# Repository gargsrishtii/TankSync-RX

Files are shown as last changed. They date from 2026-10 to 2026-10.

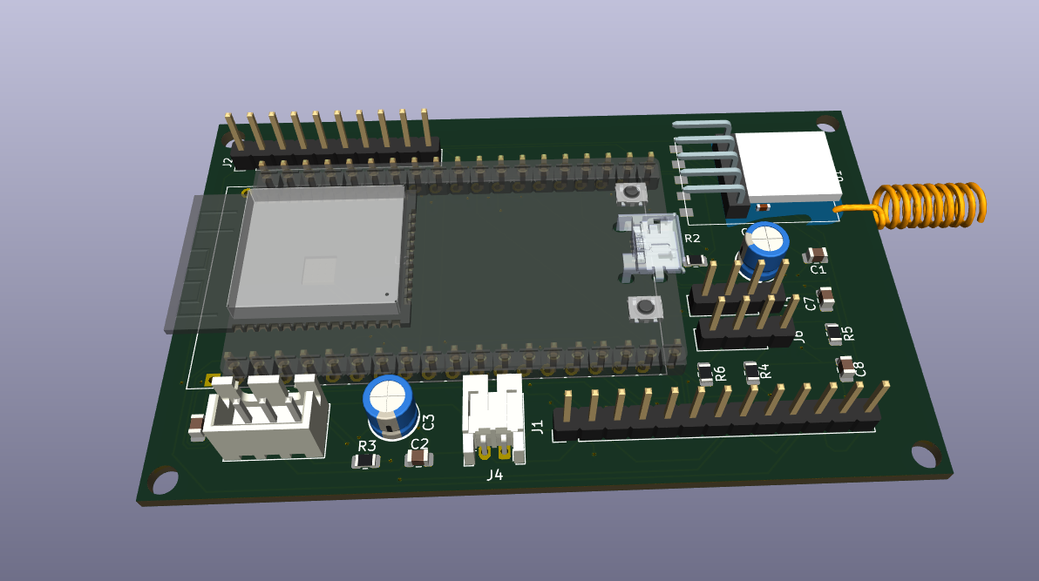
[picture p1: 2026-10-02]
images/3D view.png

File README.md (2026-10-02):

# TankSync RX — PCB Design

> 2-layer receiver board for a wireless tank monitoring system, built around the ESP32-DevKitC-VE and RYLR998 LoRa module. Designed in KiCad 10.0.

---

## Overview

TankSync RX is the receiver-side PCB of a LoRa-based wireless monitoring system. It receives sensor data transmitted over 868/915 MHz LoRa and processes it via an ESP32 for display and relay control.

**Key features:**
- ESP32-DevKitC-VE as the main controller (Wi-Fi + Bluetooth + dual-core)
- RYLR998 LoRa UART module for long-range wireless communication
- 1.3" OLED display connector (4-pin, I2C)
- WS2812B LED data line with 470Ω series resistor
- 3x status LEDs with 330Ω current-limiting resistors
- JST PH 2.0mm power input connector
- JST XH 3-pin connector for external sensor/data interface
- Berg headers (13-pin + 10-pin) for future relay expansion
- Decoupling capacitors on all power rails
- GND copper pour on both layers

---

## Board Specifications

| Parameter | Value |
|---|---|
| Board size | 80 × 50 mm |
| Layers | 2 (F.Cu + B.Cu) |
| PCB thickness | 1.6 mm |
| Design tool | KiCad 10.0 |
| ERC status | 0 errors, 0 warnings |
| DRC status | 0 errors, 0 unconnected |
| Gerbers | Exported and verified |

---

## Schematic

> *See `/schematic/TankSync_RX_Schematic.pdf` for the full schematic.*

Key design decisions:
- **LORA_RST** tied to ESP32 IO12 with a 10KΩ pull-up (R2) to +3V3, allowing software-controlled LoRa reset
- **R3 (470Ω)** series data resistor from IO32 to LED_DATA line (protects ESP32 GPIO from WS2812B inrush)
- **C6, C7, C8 (100nF SMD)** decoupling capacitors placed close to ESP32 power pins
- **C3, C4 (100µF THT)** bulk decoupling on main power rail — these must remain THT (not changed to SMD)
- **J1 (13-pin) and J2 (10-pin)** Berg headers routed to ESP32 for future relay expansion board

---

## Bill of Materials

| Ref | Qty | Value / Part | Package | Description |
|---|---|---|---|---|
| U1 | 1 | RYLR998 | Castellated 5-pin SMD | REYAX 868/915MHz LoRa UART module |
| U2 | 1 | ESP32-DEVKITC-VE | 38-pin THT dual row | Espressif ESP32 dev board |
| C1 | 1 | 10µF | 0805 SMD | Power rail decoupling |
| C2 | 1 | 47µF | 0805 SMD | Power rail decoupling |
| C3, C4 | 2 | 100µF | Radial THT D5.0mm P2.5mm | Bulk decoupling — must stay THT |
| C6, C7, C8 | 3 | 100nF | 0805 SMD | ESP32 pin decoupling |
| R2 | 1 | 10KΩ | 0805 SMD | LORA_RST pull-up |
| R3 | 1 | 470Ω | 0805 SMD | LED data line series resistor |
| R4, R5, R6 | 3 | 330Ω | 0805 SMD | Status LED current limiters |
| J1 | 1 | Berg 13-pin | PinHeader 1x13 2.54mm | Relay expansion header |
| J2 | 1 | Berg 10-pin | PinHeader 1x10 2.54mm | Relay expansion header |
| J3 | 1 | 1.3" OLED | PinHeader 1x04 2.54mm | OLED display connector |
| J4 | 1 | JST PH 2-pin | JST PH S2B 2.0mm | Power input |
| J5 | 1 | JST XH 3-pin | JST XH B3B 2.5mm | External data connector |
| J6 | 1 | LED Panel | PinHeader 1x04 2.54mm | LED panel connector |

---

## Repository Structure

```
tanksync-pcb/
├── README.md
├── LICENSE
├── images/
│   └── 3D view.png
|   ├── TankSync-rx.png
|   ├── pcb-layout.png
├── gerbers/
│   └── TankSync_RX_Gerbers.zip
├── bom/
│   └── Project1.csv
└── kicad/
    ├── Project1.kicad_pro
    ├── Project1.kicad_sch
    ├── Project1.kicad_pcb
    └── Project1.net
```

---

## Gerber Files

The `/gerbers/` folder contains the complete Gerber set ready for fabrication:

| File | Layer |
|---|---|
| Project1-F_Cu.gbr | Front copper |
| Project1-B_Cu.gbr | Back copper |
| Project1-F_Silkscreen.gbr | Front silkscreen |
| Project1-B_Silkscreen.gbr | Back silkscreen |
| Project1-F_Mask.gbr | Front solder mask |
| Project1-B_Mask.gbr | Back solder mask |
| Project1-F_Paste.gbr | Front solder paste |
| Project1-B_Paste.gbr | Back solder paste |
| Project1-Edge_Cuts.gbr | Board outline |
| Project1-job.gbrjob | Gerber job file |

Recommended fab services: JLCPCB, PCBWay, OSH Park (all accept this Gerber format directly).

---

## Custom Library Dependency

This design uses two custom KiCad components from my public library:

- `MyLibrary:RYLR998_Castellated_5P` — REYAX RYLR998 LoRa module
- `MyLibrary:ESP32-DEVKITC-VE` — Espressif ESP32-DevKitC-VE dev board

**To open this project in KiCad**, you need to add the custom library first:
👉 [gargsrishtii/kicad-parts-library](https://github.com/gargsrishtii/kicad-parts-library)

Follow the installation instructions in that repo's README before opening the `.kicad_sch` or `.kicad_pcb` files.

---

## Pre-fab Checklist (Open Items)

- [ ] Zip and verify Gerbers in a Gerber viewer before ordering
- [ ] Confirm J4 JST PH part number against supplier stock
- [ ] Measure enclosure inner diameter against board outline

---

## Design Tool

- **KiCad 10.0** (PCB design)
- **EasyEDA** (cross-reference for component verification)

---

## License

This hardware design is released under **CERN-OHL-P v2** (Permissive Open Hardware License).
Free to use, modify, and manufacture — no share-alike requirement.
See [LICENSE](LICENSE) for full terms.

---

*Part of the TankSync wireless monitoring system project.*
*Custom KiCad library: [gargsrishtii/kicad-parts-library](https://github.com/gargsrishtii/kicad-parts-library)*

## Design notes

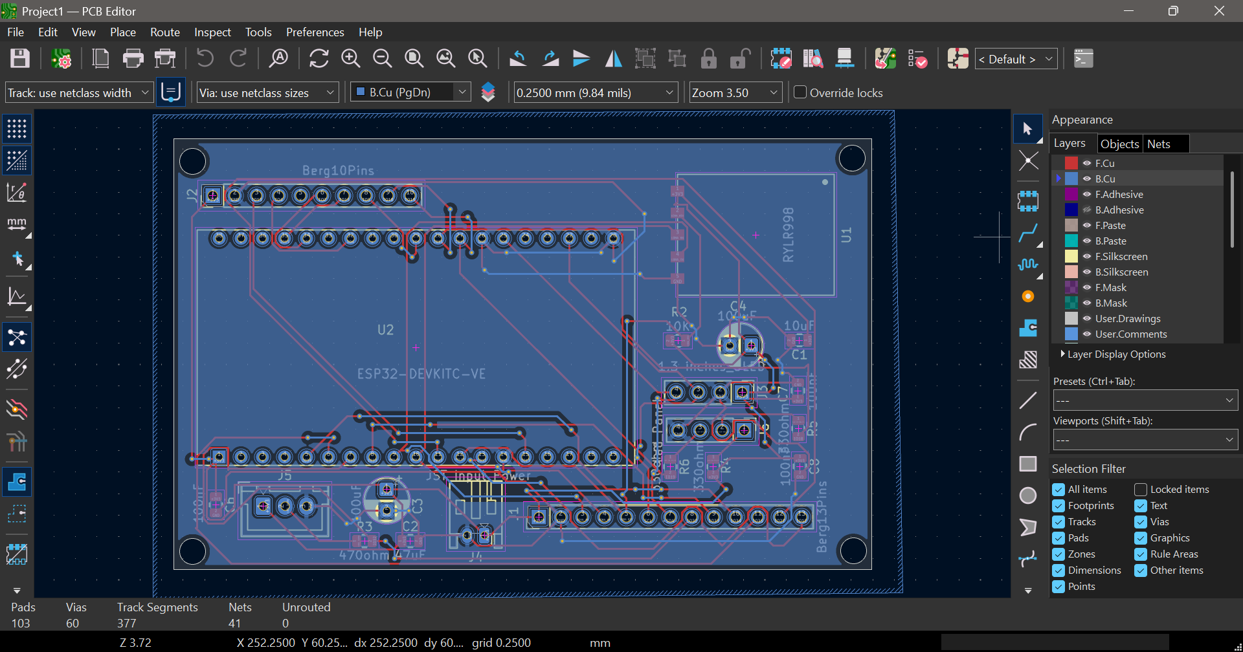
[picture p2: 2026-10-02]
images/pcb-layout.png

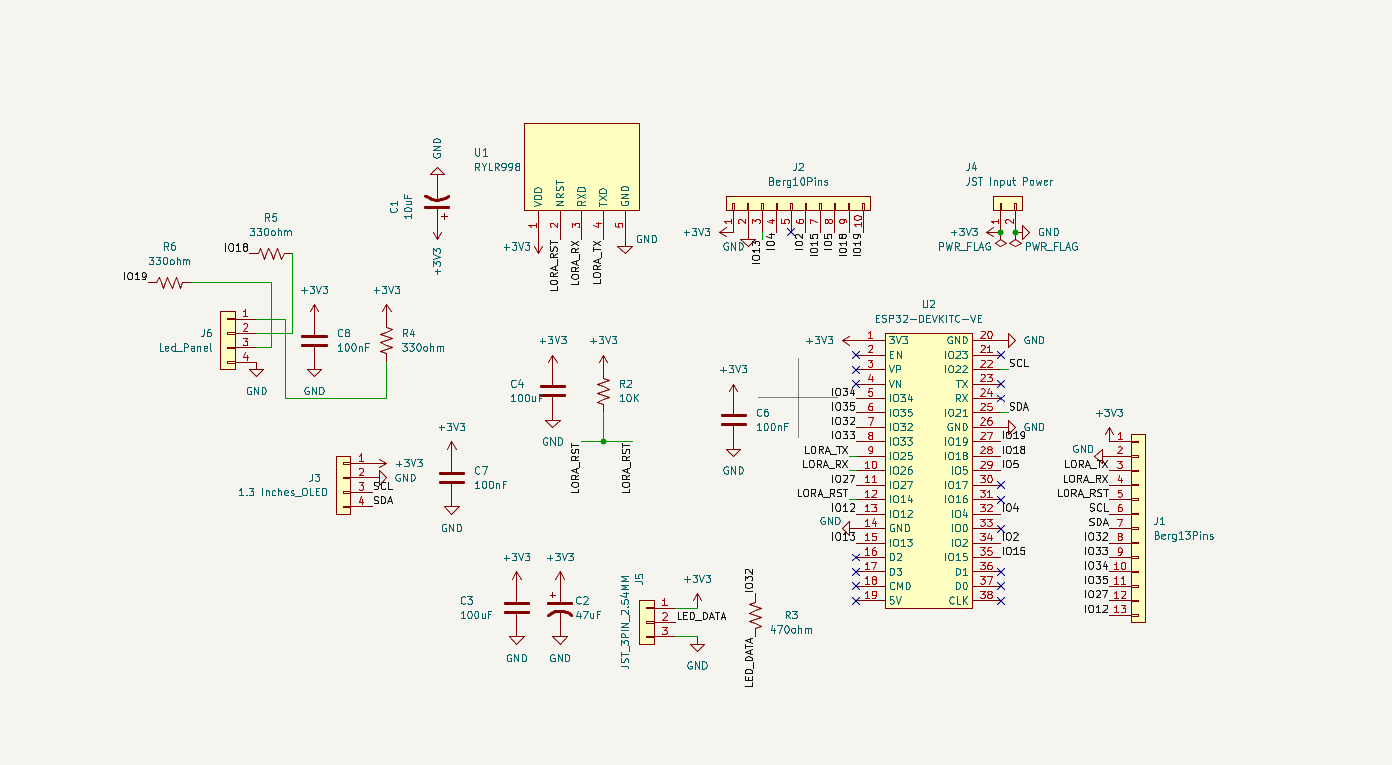
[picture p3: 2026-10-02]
images/TankSync-rx.png

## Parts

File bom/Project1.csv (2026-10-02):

Reference | Qty | Value | DNP | Exclude from BOM | Exclude from Board | Footprint | Datasheet | Description | #
C1 | 1 | 10uF |  |  |  | Capacitor_SMD:C_0805_2012Metric |  | Polarized capacitor, US symbol | 1
C2 | 1 | 47uF |  |  |  | Capacitor_SMD:C_0805_2012Metric |  | Polarized capacitor, US symbol | 2
C3,C4 | 2 | 100uF |  |  |  | Capacitor_THT:CP_Radial_D5.0mm_P2.50mm |  | Unpolarized capacitor | 3
C6,C7,C8 | 3 | 100nF |  |  |  | Capacitor_SMD:C_0805_2012Metric |  | Unpolarized capacitor | 4
J1 | 1 | Berg13Pins |  |  |  | Connector_PinHeader_2.54mm:PinHeader_1x13_P2.54mm_Vertical |  | Generic connector, single row, 01x13, script generated (kicad-library-utils/schlib/autogen/connector/) | 5
J2 | 1 | Berg10Pins |  |  |  | Connector_PinHeader_2.54mm:PinHeader_1x10_P2.54mm_Vertical |  | Generic connector, single row, 01x10, script generated (kicad-library-utils/schlib/autogen/connector/) | 6
J3 | 1 | 1.3 inches_OLED |  |  |  | Connector_PinHeader_2.54mm:PinHeader_1x04_P2.54mm_Vertical |  | Generic connector, single row, 01x04, script generated (kicad-library-utils/schlib/autogen/connector/) | 7
J4 | 1 | JST Input Power |  |  |  | Connector_JST:JST_PH_S2B-PH-K_1x02_P2.00mm_Horizontal |  | Generic connector, single row, 01x02, script generated (kicad-library-utils/schlib/autogen/connector/) | 8
J5 | 1 | JST_3PIN_2.54MM |  |  |  | Connector_JST:JST_XH_B3B-XH-A_1x03_P2.50mm_Vertical |  | Generic connector, single row, 01x03, script generated (kicad-library-utils/schlib/autogen/connector/) | 9
J6 | 1 | Led_Panel |  |  |  | Connector_PinHeader_2.54mm:PinHeader_1x04_P2.54mm_Vertical |  | Generic connector, single row, 01x04, script generated (kicad-library-utils/schlib/autogen/connector/) | 10
R2 | 1 | 10K |  |  |  | Resistor_SMD:R_0805_2012Metric |  | Resistor, US symbol | 11
R3 | 1 | 470ohm |  |  |  | Resistor_SMD:R_0805_2012Metric |  | Resistor, US symbol | 12
R4,R5,R6 | 3 | 330ohm |  |  |  | Resistor_SMD:R_0805_2012Metric |  | Resistor, US symbol | 13
U1 | 1 | RYLR998 |  |  |  | MyLibrary:RYLR998_Castellated_5P | https://reyax.com/upload/products_download/download_file/RYLR998_EN.pdf | REYAX RYLR998 868/915MHz LoRa UART Antenna Transceiver Module | 14
U2 | 1 | ESP32-DEVKITC-VE |  |  |  | MyLibrary:ESP32-DEVKITC-VE | https://docs.espressif.com/projects/esp-dev-kits/en/latest/esp32/esp32-devkitc/user_guide.html | Espressif ESP32-DevKitC-VE development board, ESP32-WROOM-32E module, 38-pin THT header | 15

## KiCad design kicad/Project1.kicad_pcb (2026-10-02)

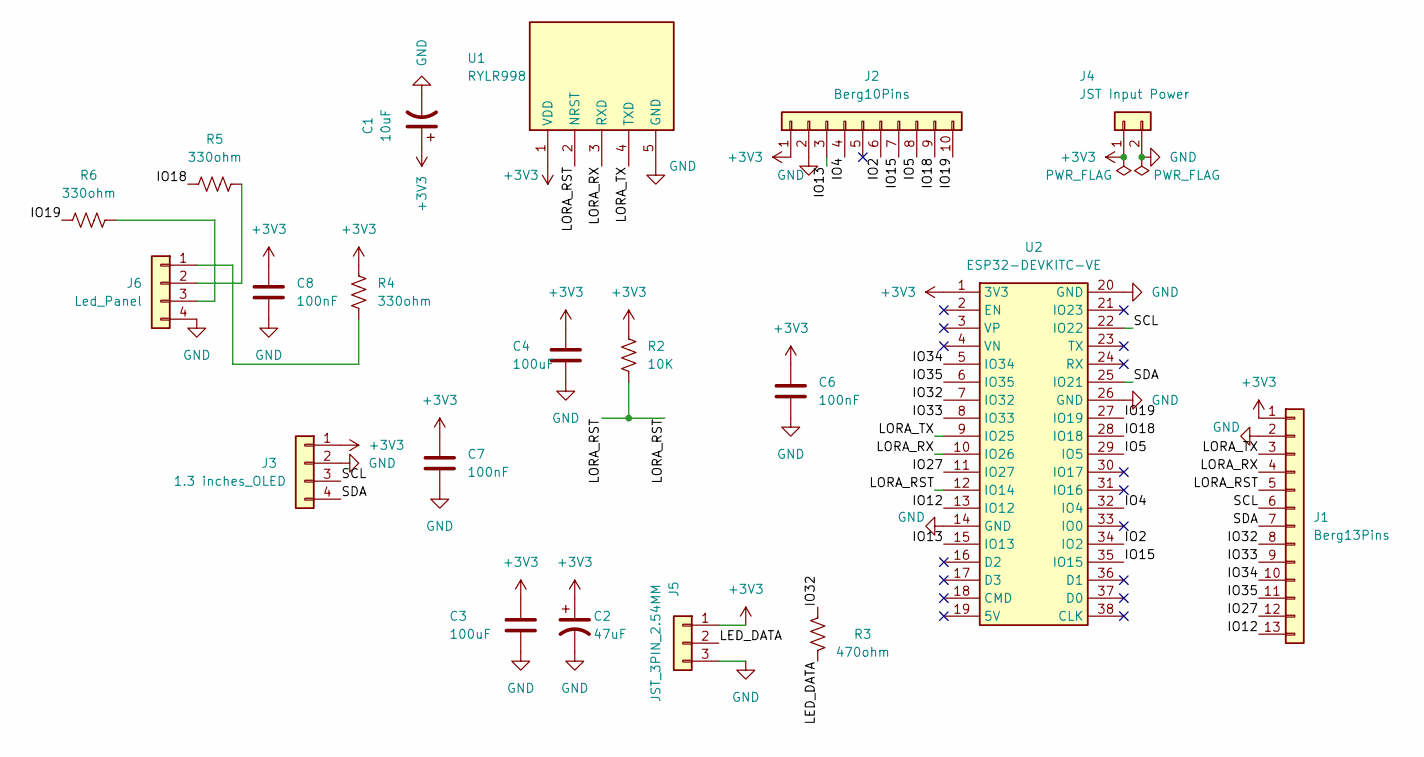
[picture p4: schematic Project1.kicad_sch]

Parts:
C1: 10uF; C_0805_2012Metric
C2: 47uF; C_0805_2012Metric
C3, C4: 100uF; CP_Radial_D5.0mm_P2.50mm
C6, C7, C8: 100nF; C_0805_2012Metric
J1: Berg13Pins; PinHeader_1x13_P2.54mm_Vertical
J2: Berg10Pins; PinHeader_1x10_P2.54mm_Vertical
J3: 1.3 inches_OLED; PinHeader_1x04_P2.54mm_Vertical
J4: JST Input Power; JST_PH_S2B-PH-K_1x02_P2.00mm_Horizontal
J5: JST_3PIN_2.54MM; JST_XH_B3B-XH-A_1x03_P2.50mm_Vertical
J6: Led_Panel; PinHeader_1x04_P2.54mm_Vertical
R2: 10K; R_0805_2012Metric
R3: 470ohm; R_0805_2012Metric
R4, R5, R6: 330ohm; R_0805_2012Metric
U1: RYLR998; RYLR998_Castellated_5P
U2: ESP32-DEVKITC-VE

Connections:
+3V3: C1.1, C2.1, C3.1, C4.1, C6.1, C7.1, C8.1, J1.1, J2.1, J3.1, J4.1, J5.1, R2.2, R4.2, U1.1 (VDD), U2.1 (3V3)
/IO2: J2.6, U2.34 (IO2)
/IO4: J2.4, U2.32 (IO4)
/IO5: J2.8, U2.29 (IO5)
/IO12: J1.13, U2.13 (IO12)
/IO13: J2.3, U2.15 (IO13)
/IO15: J2.7, U2.35 (IO15)
/IO18: J2.9, R5.2, U2.28 (IO18)
/IO19: J2.10, R6.2, U2.27 (IO19)
/IO27: J1.12, U2.11 (IO27)
/IO32: J1.8, R3.2, U2.7 (IO32)
/IO33: J1.9, U2.8 (IO33)
/IO34: J1.10, U2.5 (IO34)
/IO35: J1.11, U2.6 (IO35)
/LED_DATA: J5.2, R3.1
/LORA_RST: J1.5, R2.1, U1.2 (NRST), U2.12 (IO14)
/LORA_RX: J1.4, U1.3 (RXD), U2.10 (IO26)
/LORA_TX: J1.3, U1.4 (TXD), U2.9 (IO25)
/SCL: J1.6, J3.3, U2.22 (IO22)
/SDA: J1.7, J3.4, U2.25 (IO21)
GND: C1.2, C2.2, C3.2, C4.2, C6.2, C7.2, C8.2, J1.2, J2.2, J3.2, J4.2, J5.3, J6.4, U1.5 (GND), U2.14 (GND), U2.20 (GND), U2.26 (GND)
unnamed: J6.1, R4.1
unnamed: J6.2, R5.1
unnamed: J6.3, R6.1

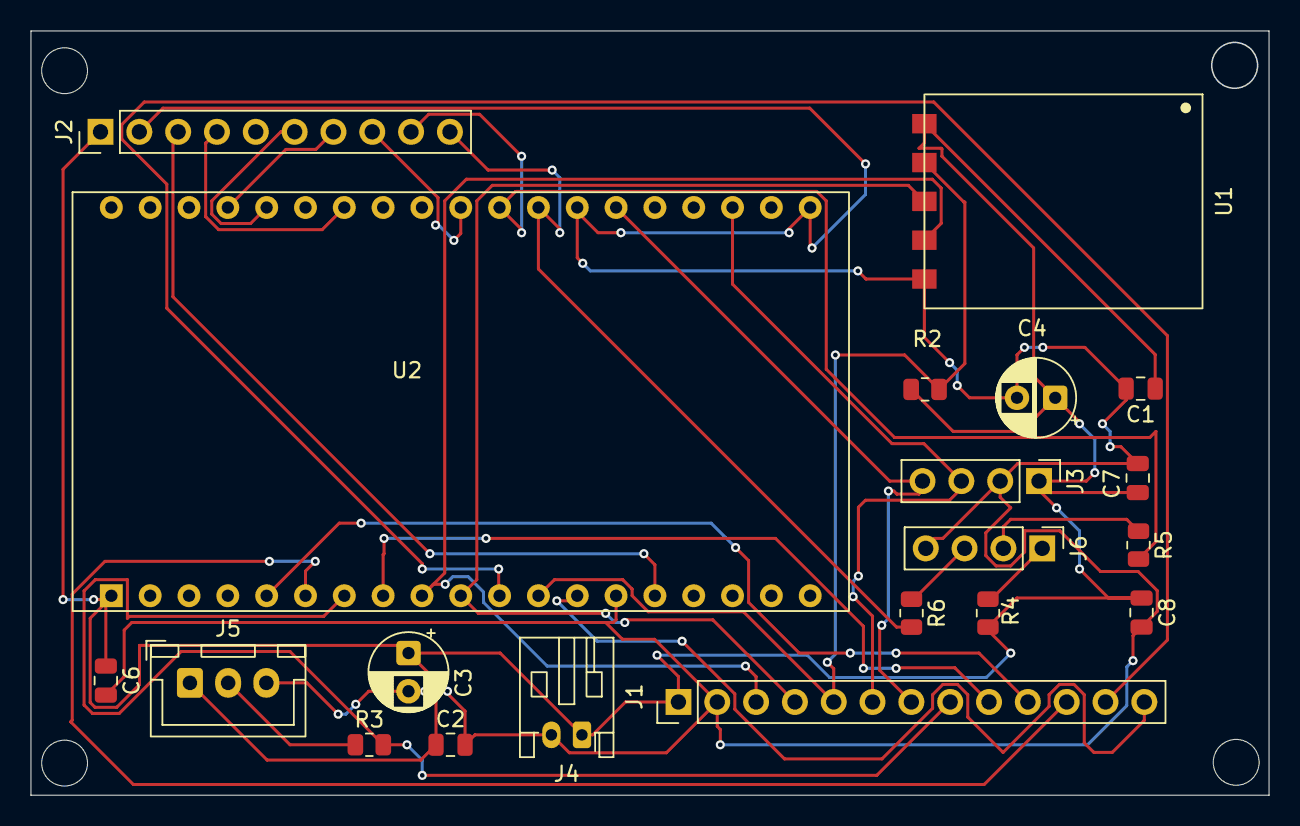
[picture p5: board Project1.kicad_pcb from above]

Board: 2 copper layers, 81.0 x 50.0 mm, 20 parts (0 on the bottom side), 24 nets.

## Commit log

2026-10-02 Add KiCad project files
    [Project1.kicad_pcb, Project1.kicad_sch]
2026-10-02 Add Gerber files
2026-10-02 Add BOM
    [Project1.csv]
2026-10-02 Add Schematic png
